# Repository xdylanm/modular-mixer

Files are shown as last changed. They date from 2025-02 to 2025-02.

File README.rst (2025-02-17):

Mixer+ Module
=============

The Mixer+ module includes a basic three channel mixer as well as an attenuverter with the option to add distortion to the output signal.

3 Channel Mixer
---------------

The 3 channel mixer is designed for a maximum of unit gain per channel. 

* DC coupled inputs
* Inverting and non-inverting outputs
* Simple output level indicator (red LED illuminates when :math:`V_{pp} \gtrapprox 9V`)

Attenuverter with Distortion
----------------------------

The input of the attenuverter is connected internally (normaled) to the non-inverting output of the mixer. The internal connection is broken when an external connection is made. The attenuverter output can be optionally distorted or offset with a DC voltage. 

* Input normaled to the non-inverting output of the mixer and is DC coupled
* Gain from -1 to 1
* Optional back-to-back diode distortion (dirty/clean switch)
* DC offset control adds -6 to +6V DC to output signal

References
----------

#. Moritz Klein, "Designing a 3-channel mixer with diode distortion from scratch", `Youtube <https://www.youtube.com/watch?v=q8tmUgaXrEQ>`_
#. Ray Wilson, "Ultra-Simple Mono Audio Mixer #1", `Music From Outer Space <https://musicfromouterspace.com/analogsynth_new/OLDIESBUTGOODIES/AUDIOMIXER/monomixer.html>`_

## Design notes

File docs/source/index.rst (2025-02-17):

.. Template documentation master file, created by
   sphinx-quickstart on Mon Sep 16 20:44:51 2024.
   You can adapt this file completely to your liking, but it should at least
   contain the root `toctree` directive.

.. include:: ../../README.rst

.. only:: builder_html

   Schematic
   ---------

   Download the :download:`schematic <_static/mixer.pdf>`.

.. toctree::
   :maxdepth: 2
   :caption: Documentation

   theory
   assembly

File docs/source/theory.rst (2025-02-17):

Theory of Operation
===================

Attenuverter
------------

Reference: https://www.befaco.org/dual-atenuverter/

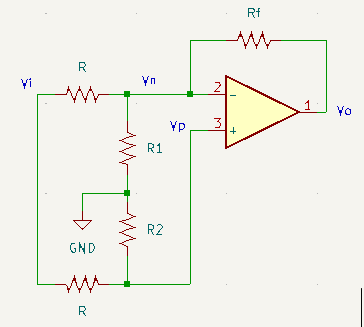
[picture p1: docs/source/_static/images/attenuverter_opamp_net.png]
Attenuverter


Voltage divider R1-R2 is implemented with a fixed R (:math:`R_1'`) in series with a variable resistor (pot) with max R :math:`R_2'`.

.. math::

    0 &= \frac{V_p - V_i}{R} + \frac{V_p}{R_2} \\
    \to V_p &= \frac{R_2 V_i}{R_2 + R}\quad\mathrm{with}\quad V_p = V_n \\
    0 &= \frac{V_n - V_i}{R} + \frac{V_n}{R_1}+\frac{V_n-V_o}{R_f}  \\
    \to 0 &= V_n - V_i + \frac{R}{R_1}V_n + \frac{R}{R_f}V_n - \frac{R}{R_f}V_o \\
    \to \frac{R}{R_f}V_o &= V_n\left(1 + \frac{R}{R_1} + \frac{R}{R_f}\right) - V_i \\
    \to \frac{R}{R_f}V_o &= \left[\frac{R_2}{R_2 + R}\left(1 + \frac{R}{R_1} + \frac{R}{R_f}\right) - 1 \right]V_i \\
    \mathrm{let}\ R_f &= R \\
    \to V_o &= \left[\frac{R_2}{R_2 + R}\left(\frac{2R_1 +  R}{R_1}\right) - 1 \right]V_i

If :math:`R_2=0` (potentiometer wiper is set to the end stop), :math:`V_o = -V_i` . Choosing the maximum potentiometer value to be :math:`R_2'=R` and the remaining fixed resistance :math:`R_1=R_1'` 

.. math::

    2 &= \frac{R_2}{R_2+R}\left(\frac{2R_1 + R}{R_1}\right) = \frac{R}{2R}\left(\frac{2R_1' + R}{R_1'}\right) \\
    \to 4R_1' &= 2R_1' + R \to R_1' = \frac{1}{2}R

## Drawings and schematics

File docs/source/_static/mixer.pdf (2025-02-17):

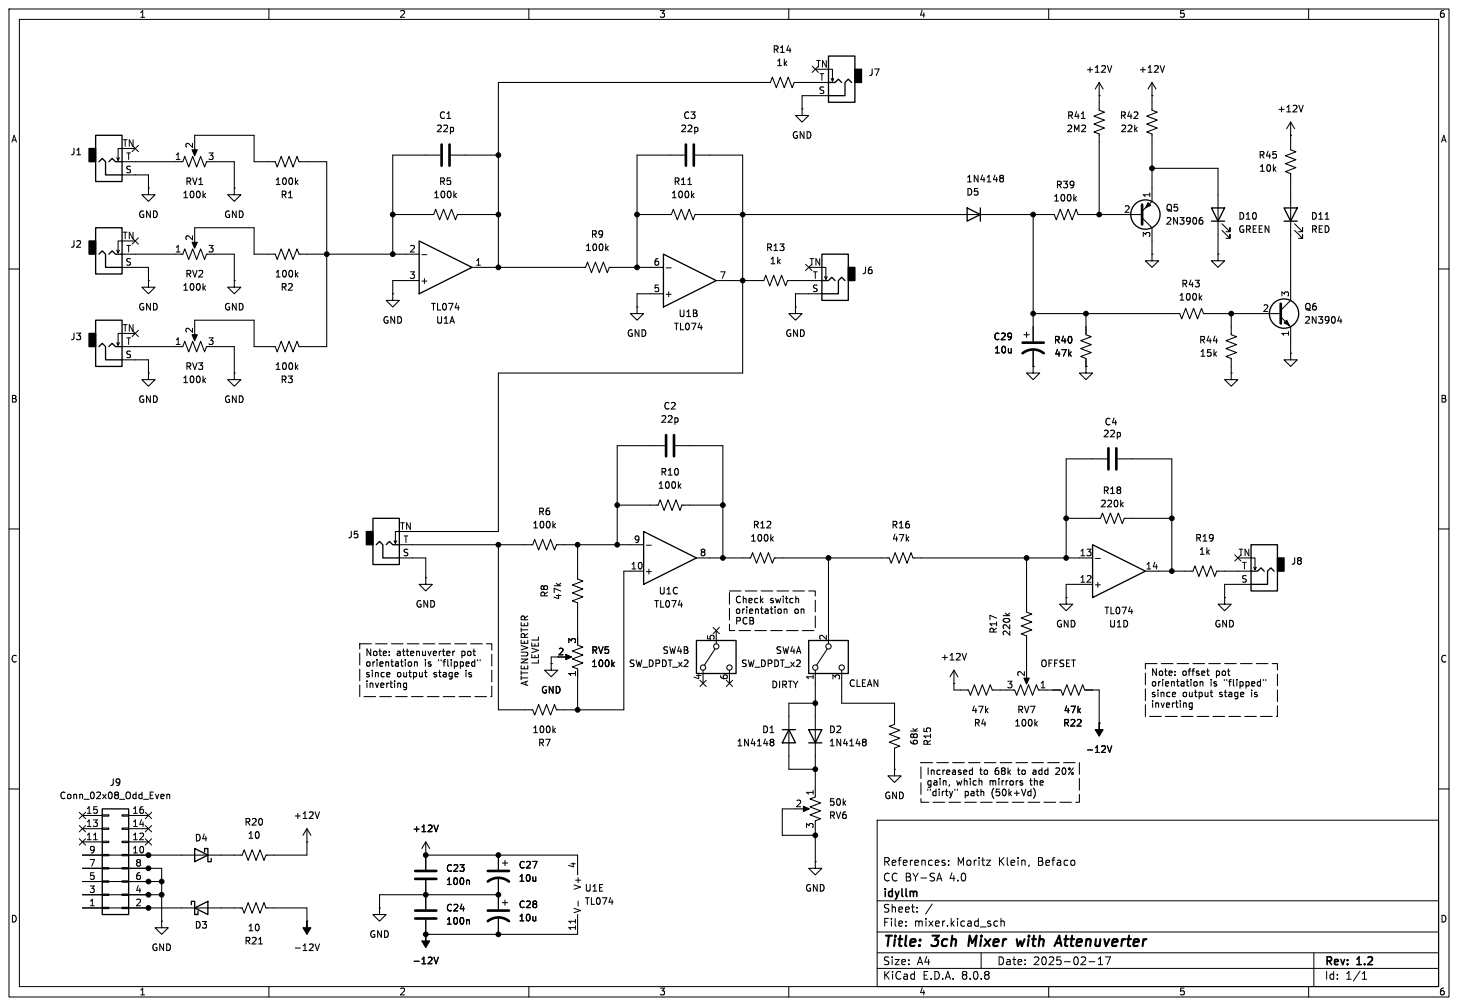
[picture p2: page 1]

idyllm
Id: 1/1 Title: 3ch Mixer with Attenuverter File: mixer.kicad_sch Sheet: /

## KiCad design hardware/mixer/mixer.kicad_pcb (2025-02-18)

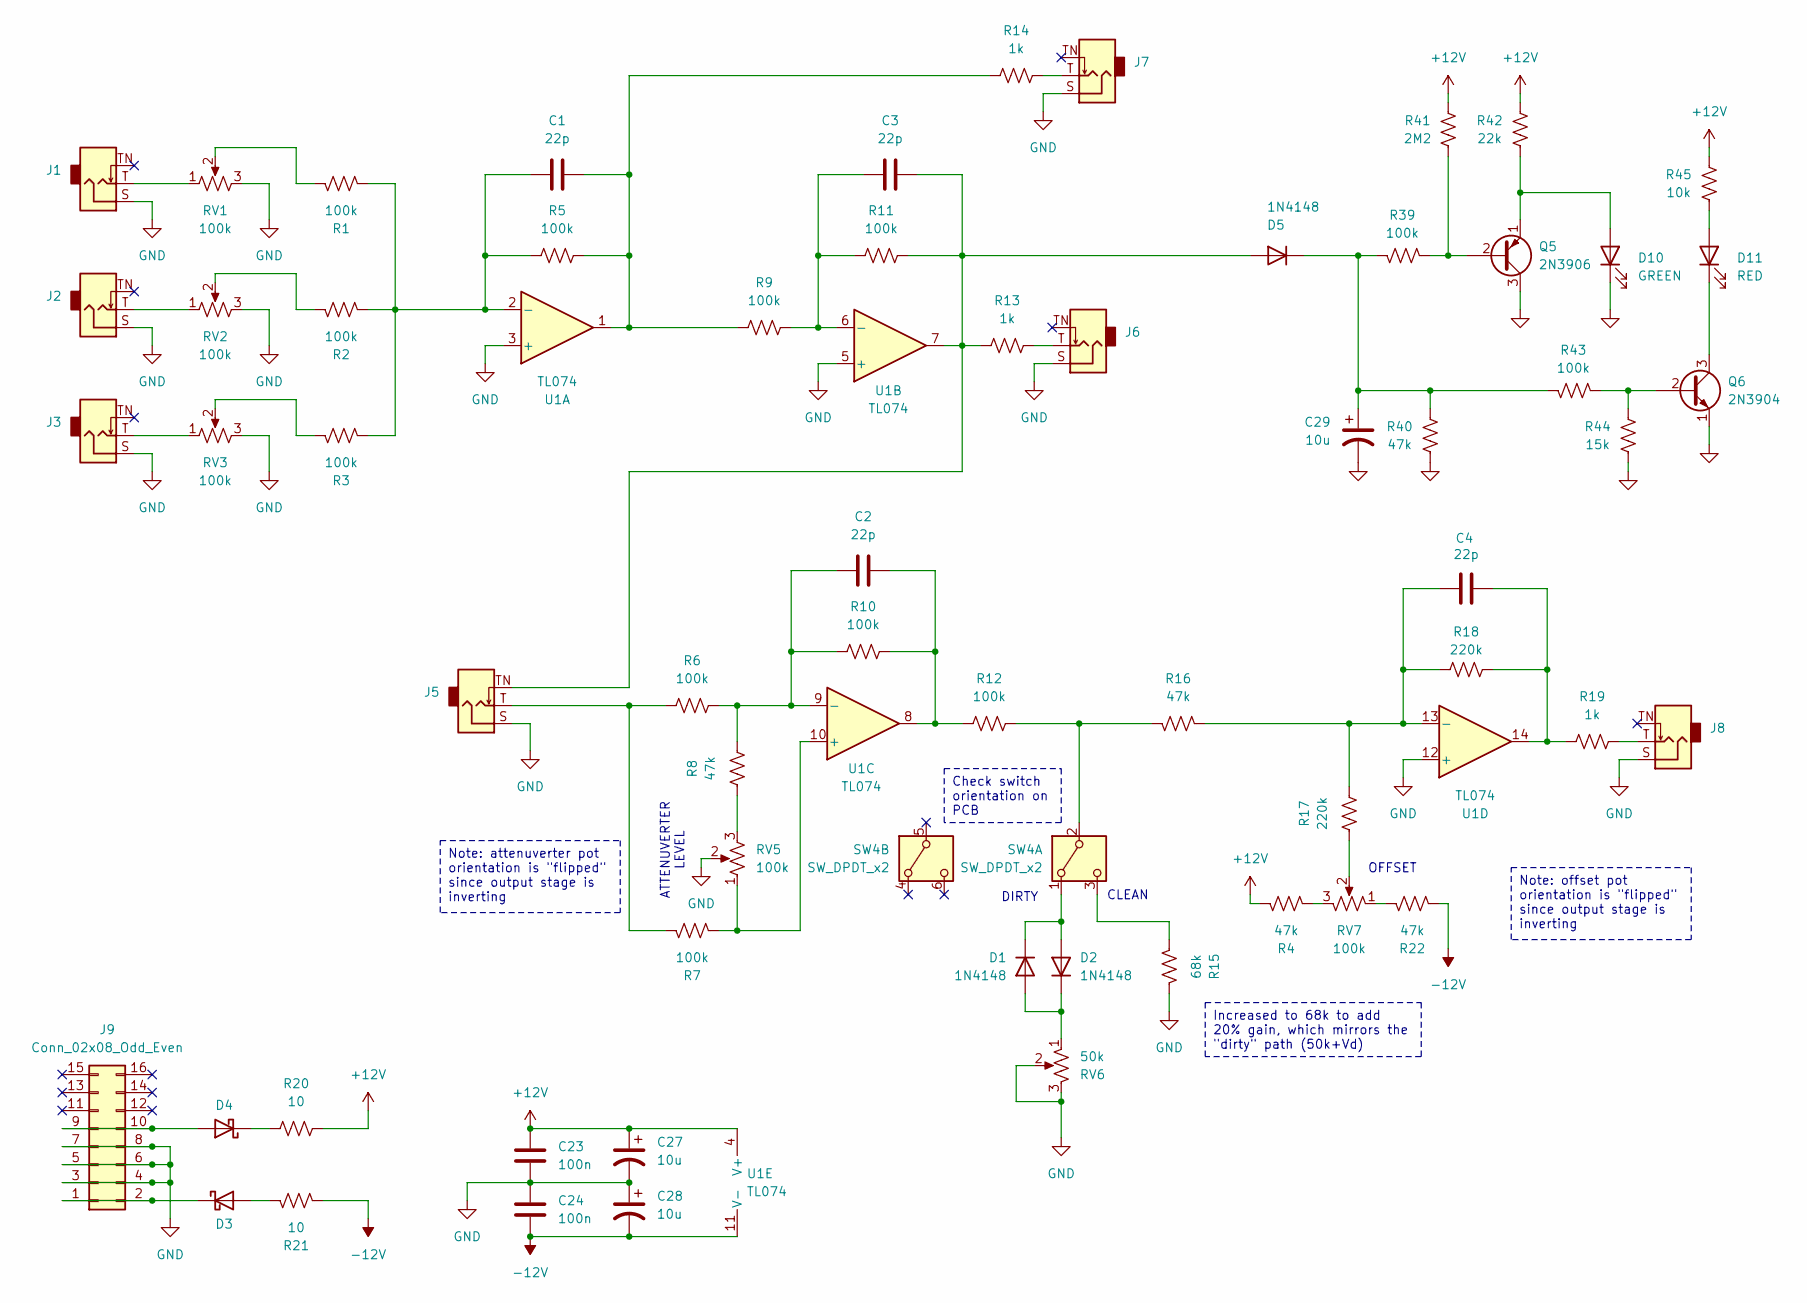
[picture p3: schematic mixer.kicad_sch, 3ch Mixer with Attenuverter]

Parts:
C1: 22p; C_Disc_D5.0mm_W2.5mm_P5.00mm
C2, C3, C4: 22p; C_Disc_D5.0mm_W2.5mm_P2.50mm
C23, C24: 100n; C_Disc_D5.0mm_W2.5mm_P2.50mm
C27, C28, C29: 10u; CP_Radial_D4.0mm_P2.00mm
D1, D2: 1N4148; D_DO-35_SOD27_P2.54mm_Vertical_AnodeUp
D3: D_Schottky; D_DO-41_SOD81_P2.54mm_Vertical_AnodeUp
D4: D_Schottky; D_DO-41_SOD81_P2.54mm_Vertical_KathodeUp
D5: 1N4148; D_DO-35_SOD27_P12.70mm_Horizontal
D10: GREEN; LED_D3.0mm_Clear
D11: RED; LED_D3.0mm_Clear
J1, J2, J3, J5, J6, J7, J8: AudioJack2_SwitchT; Jack_3.5mm_QingPu_WQP-PJ301M-12_Vertical
J9: Conn_02x08_Odd_Even; IDC-Header_2x08_P2.54mm_Vertical
Q5: 2N3906; TO-92_Inline_Wide
Q6: 2N3904; TO-92_Inline_Wide
R1, R2, R3, R5, R6, R7, R10, R11, R12, R39, R43: 100k; R_Axial_DIN0204_L3.6mm_D1.6mm_P2.54mm_Vertical
R4, R8, R22, R40: 47k; R_Axial_DIN0204_L3.6mm_D1.6mm_P2.54mm_Vertical
R9: 100k; R_Axial_DIN0207_L6.3mm_D2.5mm_P15.24mm_Horizontal
R13, R14, R19: 1k; R_Axial_DIN0204_L3.6mm_D1.6mm_P2.54mm_Vertical
R15: 68k; R_Axial_DIN0204_L3.6mm_D1.6mm_P2.54mm_Vertical
R16: 47k; R_Axial_DIN0207_L6.3mm_D2.5mm_P15.24mm_Horizontal
R17, R18: 220k; R_Axial_DIN0204_L3.6mm_D1.6mm_P2.54mm_Vertical
R20: 10; R_Axial_DIN0204_L3.6mm_D1.6mm_P2.54mm_Vertical
R21: 10; R_Axial_DIN0207_L6.3mm_D2.5mm_P10.16mm_Horizontal
R41: 2M2; R_Axial_DIN0204_L3.6mm_D1.6mm_P2.54mm_Vertical
R42: 22k; R_Axial_DIN0204_L3.6mm_D1.6mm_P2.54mm_Vertical
R44: 15k; R_Axial_DIN0204_L3.6mm_D1.6mm_P2.54mm_Vertical
R45: 10k; R_Axial_DIN0204_L3.6mm_D1.6mm_P2.54mm_Vertical
RV1, RV2, RV3, RV5, RV7: 100k; Potentiometer_Bourns_PTV09A-1_Single_Vertical
RV6: 50k; Potentiometer_Bourns_PTV09A-1_Single_Vertical
SW4: SW_DPDT_x2; SW_DPDT_13mm_x_13mm_P5.00mm
U1: TL074; DIP-14_W7.62mm_Socket

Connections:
+12V: C23.2, C27.1, R4.1, R20.2, R41.2, R42.2, R45.2, U1.4 (V+)
-12V: C24.1, C28.2, R21.2, R22.2, U1.11 (V-)
GND: C23.1, C24.2, C27.2, C28.1, C29.2, D10.1 (K), J1.S, J2.S, J3.S, J5.S, J6.S, J7.S, J8.S, J9.3, J9.4, J9.5, J9.6, J9.7, J9.8, Q5.3 (C), Q6.1 (E), R15.1, R40.1, R44.1, RV1.3, RV2.3, RV3.3, RV5.2, RV6.2, RV6.3, U1.3 (+), U1.5 (+), U1.12 (+)
unnamed: C1.2, R5.2, R9.1, R14.1, U1.1
unnamed: C2.2, R10.2, R12.1, U1.8
unnamed: C4.2, R18.2, R19.1, U1.14
unnamed: D1.2 (A), D2.1 (K), RV6.1
unnamed: D1.1 (K), D2.2 (A), SW4.1 (A)
unnamed: D3.2 (A), R21.1
unnamed: D3.1 (K), J9.1, J9.2
unnamed: D4.2 (A), J9.9, J9.10
unnamed: D4.1 (K), R20.1
unnamed: C3.2, D5.2 (A), J5.TN, R11.2, R13.1, U1.7
unnamed: C29.1, D5.1 (K), R39.2, R40.2, R43.2
unnamed: D10.2 (A), Q5.1 (E), R42.1
unnamed: D11.2 (A), R45.1
unnamed: D11.1 (K), Q6.3 (C)
unnamed: J1.T, RV1.1
unnamed: J2.T, RV2.1
unnamed: J3.T, RV3.1
unnamed: J5.T, R6.1, R7.1
unnamed: J6.T, R13.2
unnamed: J7.T, R14.2
unnamed: J8.T, R19.2
unnamed: Q5.2 (B), R39.1, R41.1
unnamed: Q6.2 (B), R43.1, R44.2
unnamed: R1.1, RV1.2
unnamed: R2.1, RV2.2
unnamed: R3.1, RV3.2
unnamed: R4.2, RV7.3
unnamed: R8.1, RV5.3
unnamed: R17.1, RV7.2
unnamed: R22.1, RV7.1
unnamed: R12.2, R16.2, SW4.2 (B)
unnamed: R15.2, SW4.3 (C)
unnamed: C1.1, R1.2, R2.2, R3.2, R5.1, U1.2 (-)
unnamed: C3.1, R9.2, R11.1, U1.6 (-)
unnamed: R7.2, RV5.1, U1.10 (+)
unnamed: C2.1, R6.2, R8.2, R10.1, U1.9 (-)
unnamed: C4.1, R16.1, R17.2, R18.1, U1.13 (-)

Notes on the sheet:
Increased to 68k to add 20% gain, which mirrors the "dirty" path (50k+Vd)
Note: attenuverter pot orientation is "flipped" since output stage is inverting
Note: offset pot orientation is "flipped" since output stage is inverting
Check switch orientation on PCB
CLEAN
ATTENUVERTER LEVEL
DIRTY
OFFSET

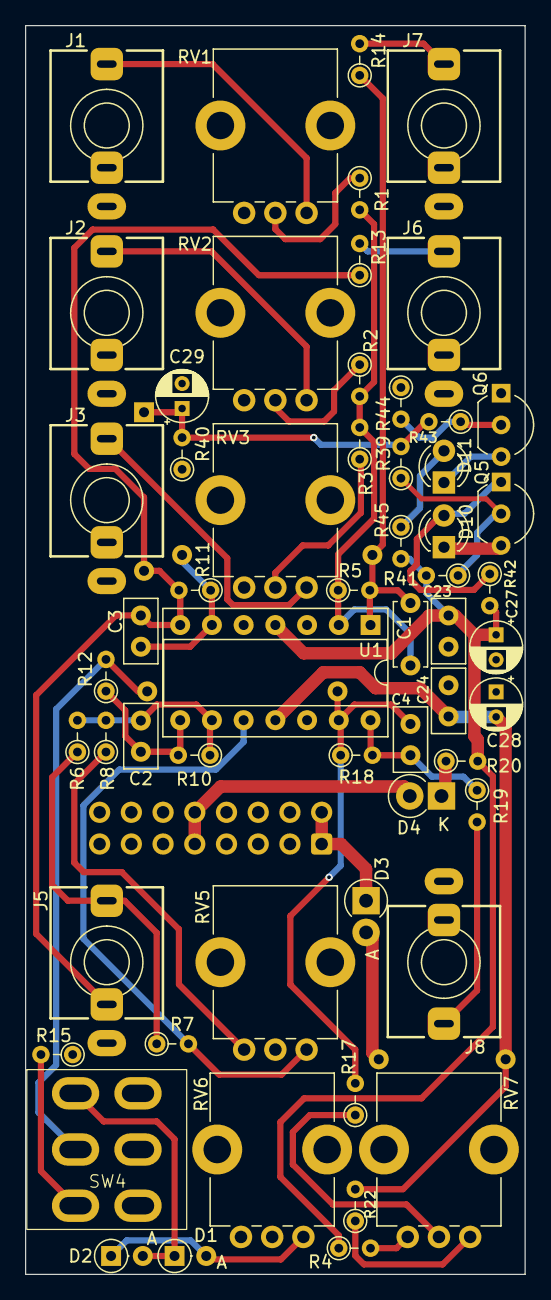
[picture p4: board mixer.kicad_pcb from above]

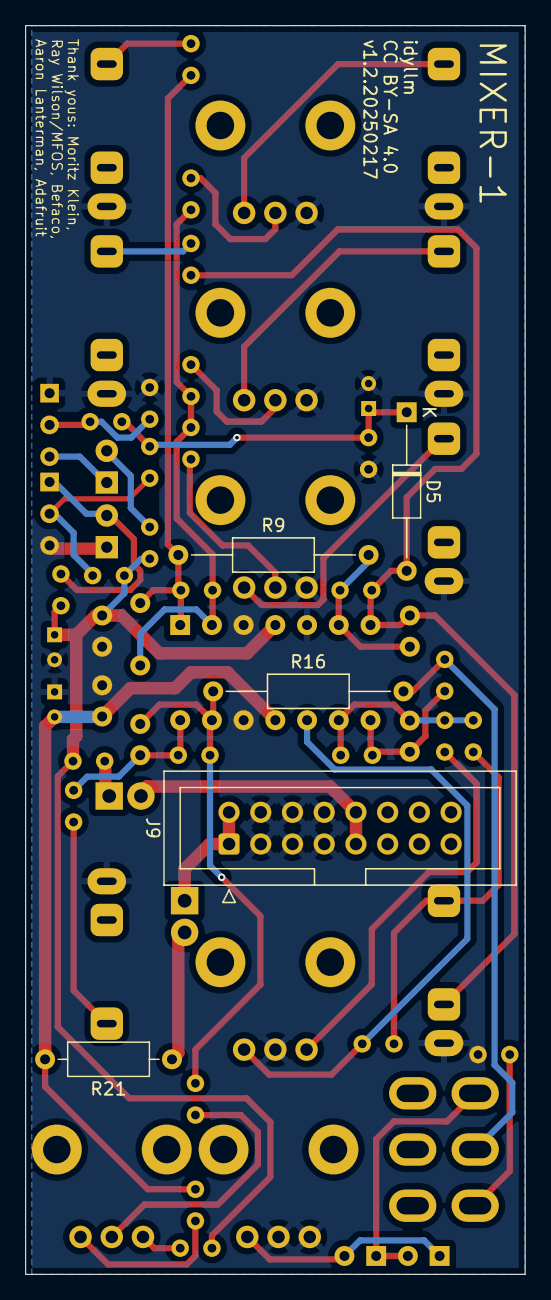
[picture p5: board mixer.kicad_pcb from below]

Board: 2 copper layers, 40.0 x 100.0 mm, 63 parts (5 on the bottom side), 40 nets.

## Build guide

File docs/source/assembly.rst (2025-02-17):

Assembly Guide
==============

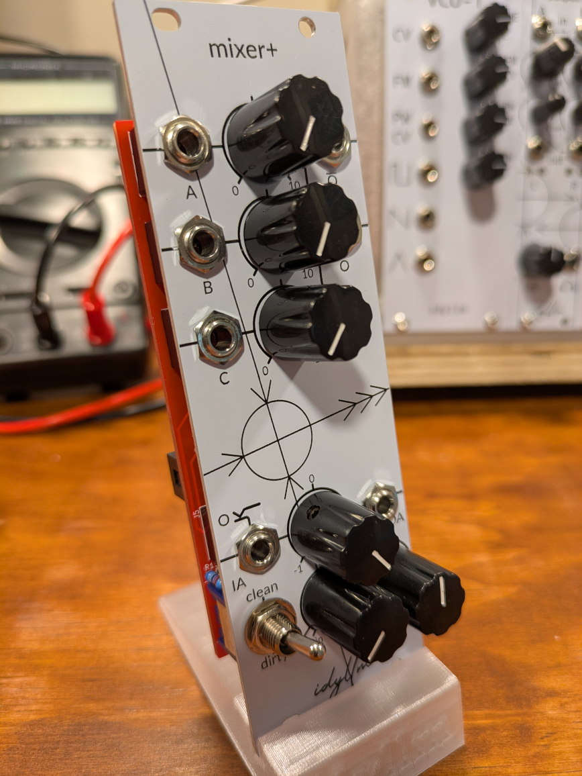
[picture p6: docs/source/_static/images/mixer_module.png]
Mixer+ Module


Placing Components
------------------

#. Backside resistors: R9, R16 
#. DIP socket: U1
#. Ceramic capacitors: C1-C4, C23, C24
#. 100k resistors: R1-R3, R5-R7, R10-R12
#. 47k resistors: R8, R4, R22, R40
#. Remaining attenuverter resistors: R25, R17, R18
#. Output resistors: R13, R14, R19
#. Power input resistors and electrolytic capacitors:

    * R20, R21 (backside). Alternative: ferite beads
    * C27-C29
    * D3, D4

#. Signal diodes: D1, D2, D5 (backside)
#. Output level indicator circuit:

    * R39-R45
    * Q5, Q6
    * *do not populate LEDs yet*

#. Audio jacks: J1-J3, J5-J8
#. 50k (B503) potentiometer: RV6
#. 100k (B104) potentiometers: 

    * no detent: RV1-RV3, RV5
    * with detent: RV7

#. DPDT switch: SW4

Before adding LEDs (D10 and D11), add the spacing washers for the audio jacks and fit the faceplate

Faceplate and Knobs
-------------------

#. Add 0.6mm M6 nylon washers over the audio jacks.
#. Fit the faceplate and solder the LEDs

    * Insert the LEDs (D10 and D11) in the holes in the PCB (*observe polarity & colour*). 
    * Ensure that the faceplate fits close. It can be secured with nuts for the audio jacks or an elastic while mounting the LEDs
    * Adjust the LEDs so that they project through their holes in the faceplate then solder in place.

#. Attach the faceplate with the nuts for the audio jacks and the switch. An additional washer can be used for the switch on the front of the faceplate.
#. Attach the knobs.

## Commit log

2025-02-17 Moved mixer module from toolbox to own repo, updated docs based on 1.1 build
    [extras.kicad_sch, mixer.kicad_pcb, mixer.kicad_sch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]
2025-02-18 changed R15 to 68k
    [mixer.kicad_pcb]

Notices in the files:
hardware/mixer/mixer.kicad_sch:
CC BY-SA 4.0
